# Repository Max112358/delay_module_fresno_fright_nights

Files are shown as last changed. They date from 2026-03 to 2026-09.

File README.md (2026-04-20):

This module can control a 12v signal on a time delay. Originally intended for the "horn scare" at Fresno Fright Nights. It takes an input (anywhere from 5v to 24v) to trigger the output.

The output turns on when triggered and stays on according to the potentiometer (knob) labeled on time.
After that it turns off for the duration based on the off time knob. It ignores further inputs during this time.
After the off time has elapsed, it resets itself.

There is a switch onboard that lets you reverse the timing. Off first, then on.

The idea is that when someone walks close to a car we have placed as a prop, it honks the horn immediately, jump scaring them. If a group of several people walk past, you dont want the horn to keep going off for each person. They would have seen the first person get honked, and so would be expecting it. Further honks would just be annoying. So it ignores further triggers until the off time delay has been reached.

The gerber file is meant to be sent to board houses so they can make the board. The epro file is for easyedya.com, my preferred board editor. The c++ code is for arduino, and runs on the attiny85 chip the board uses.

For the STL files, its designed to use M3 heat insertable nuts into the plastic. You could probably get away with a wood screw around that same size also.

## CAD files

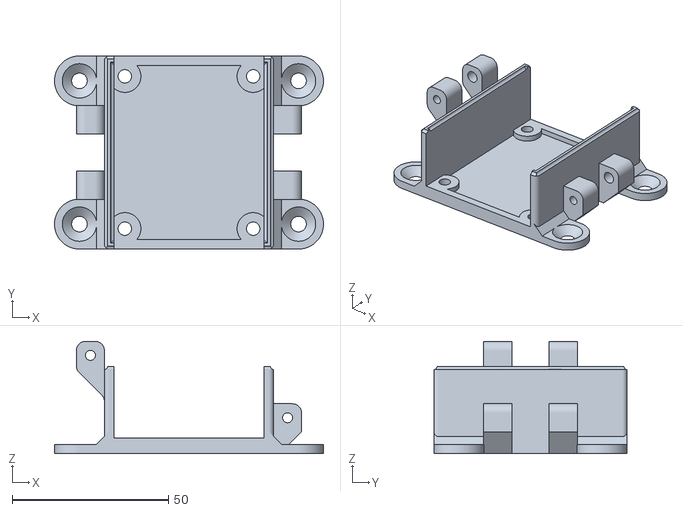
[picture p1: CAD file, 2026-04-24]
STL_files/clasp box/lower box.stl
86.2 x 61.9 x 36.0

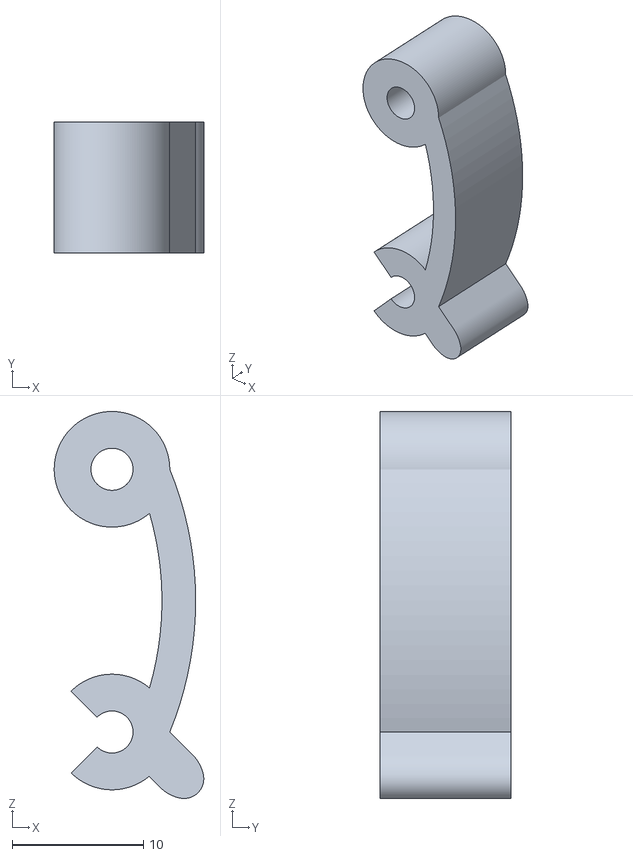
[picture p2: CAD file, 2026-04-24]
STL_files/clasp box/clasp.stl
11.4 x 10.0 x 29.5

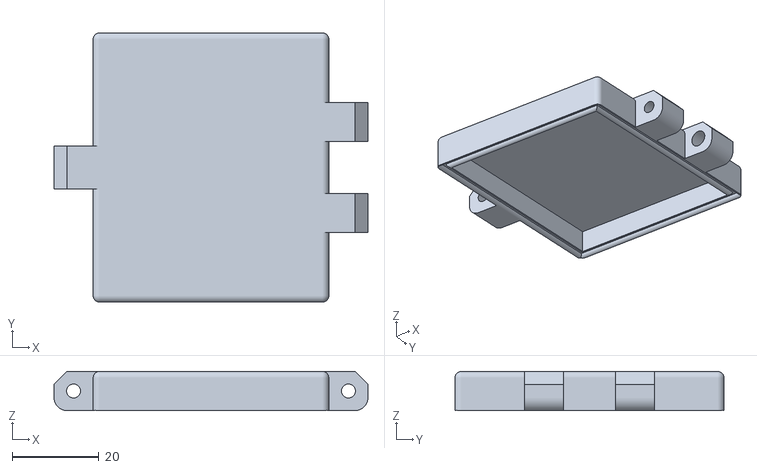
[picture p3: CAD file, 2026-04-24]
STL_files/clasp box/lid.stl
72.2 x 61.9 x 9.00

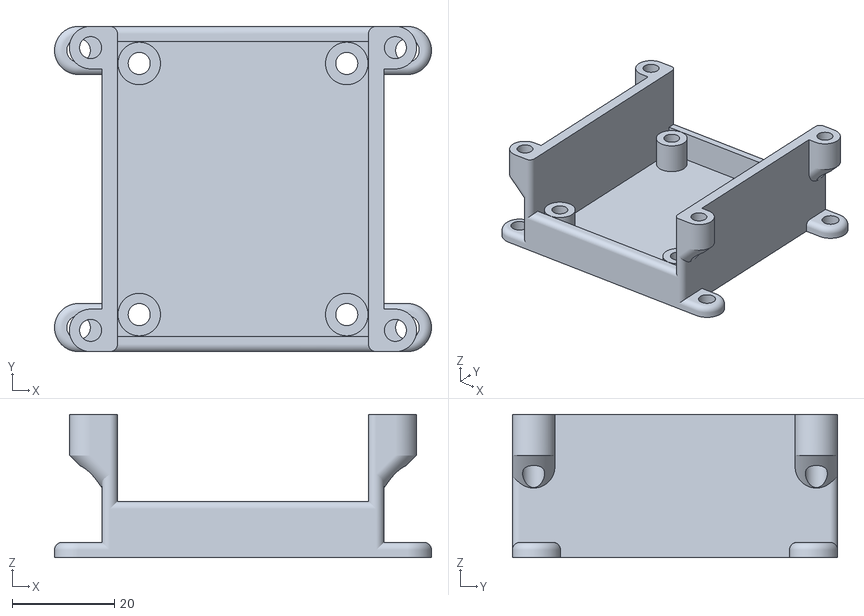
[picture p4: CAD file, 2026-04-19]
STL_files/screw closure box/lower box.stl
73.6 x 63.5 x 28.0

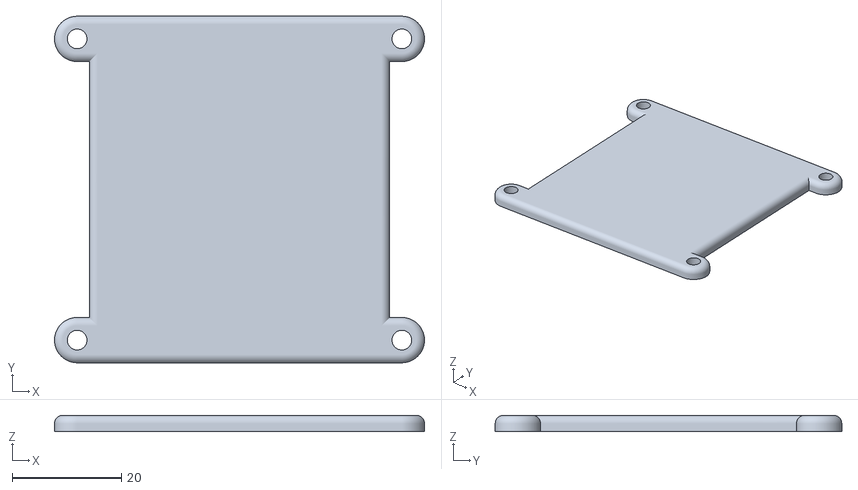
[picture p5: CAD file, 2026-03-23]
STL_files/screw closure box/lid.stl
67.8 x 63.5 x 3.00

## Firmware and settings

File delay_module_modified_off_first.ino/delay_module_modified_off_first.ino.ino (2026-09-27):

// Pin Definitions (Using Arduino/Logical mapping)
const int triggerPin = 3;  // Physical Pin 2
const int outputPin  = 1;  // Physical Pin 6
const int onPotPin   = A1; // Physical Pin 3 (Analog 1)
const int offPotPin  = A2; // Physical Pin 7 (Analog 2)
const int modePin    = 0;  // Physical Pin 5 (Digital 0)

const long maxWaitTime = 60000; // 60,000 milliseconds is 60 seconds
const long pulseOnTime = 1000;  // 1 second fixed ON pulse

void setup() {
  pinMode(outputPin, OUTPUT);
  digitalWrite(outputPin, LOW);

  pinMode(triggerPin, INPUT);
  pinMode(modePin, INPUT); // Switch pin
}

void loop() {
  // 1. Wait for the signal on Physical Pin 2 to go HIGH
  if (digitalRead(triggerPin) == HIGH) {
    delay(50); // Debounce
    if (digitalRead(triggerPin) == LOW) return;

    // 2. Read the pots and map to time range
    int onRead  = 1023 - analogRead(onPotPin);
    int offRead = 1023 - analogRead(offPotPin);

    long onDuration  = map(onRead, 0, 1023, 0, maxWaitTime);
    long offDuration = map(offRead, 0, 1023, 0, maxWaitTime);

    // 3. Check Mode Pin (Physical Pin 5)
    // HIGH = Reversed (Wait then Pulse)
    // LOW  = Normal (Pulse then Wait)
    if (digitalRead(modePin) == HIGH) {
      // REVERSED ORDER:
      // - Wait off for offDuration
      // - Pulse ON for exactly 1 second
      // - Go OFF and wait for onDuration
      digitalWrite(outputPin, LOW);
      delay(offDuration);

      digitalWrite(outputPin, HIGH);
      delay(pulseOnTime);  // fixed 1 second pulse

      digitalWrite(outputPin, LOW);
      delay(onDuration);   // second-pot wait time
    }
    else {
      // NORMAL ORDER: ON first, then OFF
      digitalWrite(outputPin, HIGH);
      delay(onDuration);

      digitalWrite(outputPin, LOW);
      delay(offDuration);
    }

    // Loop restarts and waits for next trigger
  }
}

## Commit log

2026-03-19 Update README with additional file details
    Added information about gerber and epro files, and C++ code for Arduino.
2026-03-23 added STL files for 3d printed case
    [lid.stl, lower_box.stl]
2026-04-19 new version of board
    new ver has switch that can toggle between off first and on first. Moved button, removed unnecessary resistor, cleaned up switch markings on silkscreen, made cap hole smaller. Updated arduino code to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
    [lower box.stl, lower_box.stl]
2026-04-20 Enhance README with switch functionality and project details
    Added information about the onboard switch for reversing timing and clarified the purpose of the project.
2026-04-24 added clasp box
    New STL files for a latching box. Can be opened without a screwdriver.
    [clasp.stl, lid.stl, lower box.stl]
